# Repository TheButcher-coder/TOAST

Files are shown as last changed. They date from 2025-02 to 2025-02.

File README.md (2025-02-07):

# TOAST
TOtally Amazing Scales with blueTooth
The goal of this project is to make Bluetooth compatible scales, that connect to Espresso machines. 
Its primary goal is to be an alternative to expensive espresso scales with a timer.

# BOM
- Lolin32 esp32 Board with integrated lipo charger
- 2 1Kg Load cells with hx711 ADC boards
- 2 Capacitive touch buttons
- 1 MAX7219 driven 8 Letter 7 Segment display
- cables, prototype boards, 3d prints, ect...

Thanks to BOOKOO to make their scale software OS :) Check them out! https://github.com/kstam/esp-arduino-ble-scales
Also to warmack by implementing it on this set of HW before creating the GH

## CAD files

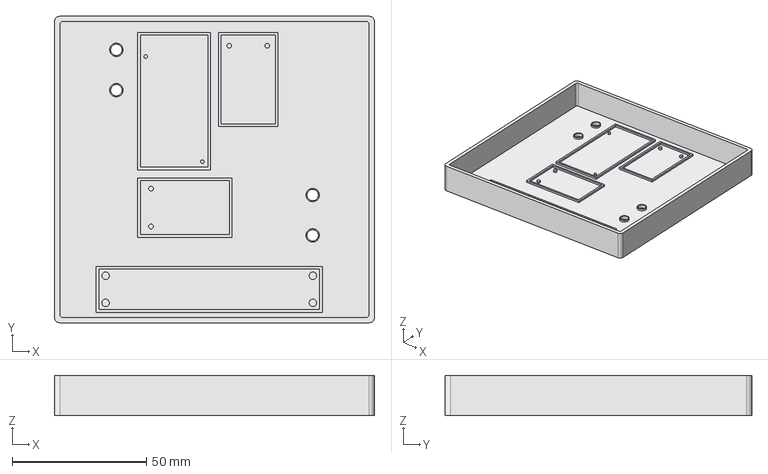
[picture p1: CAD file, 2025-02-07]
CAD/Prototyp/unteres gehäuse.FCStd
119.0 x 114.0 x 15.0 mm

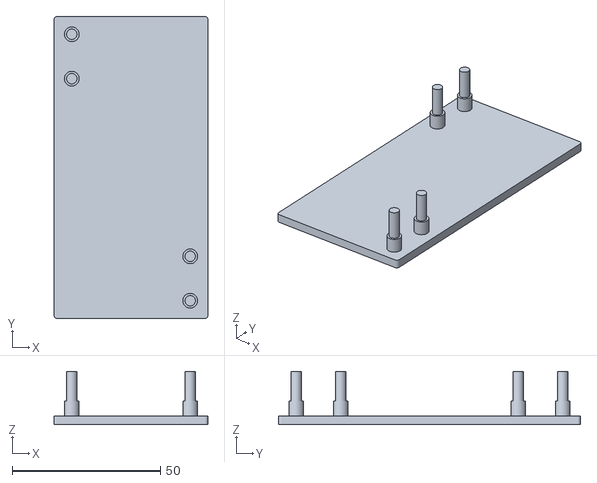
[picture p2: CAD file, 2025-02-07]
CAD/testplatte/unten-Körper.stl
52.0 x 102.0 x 18.0

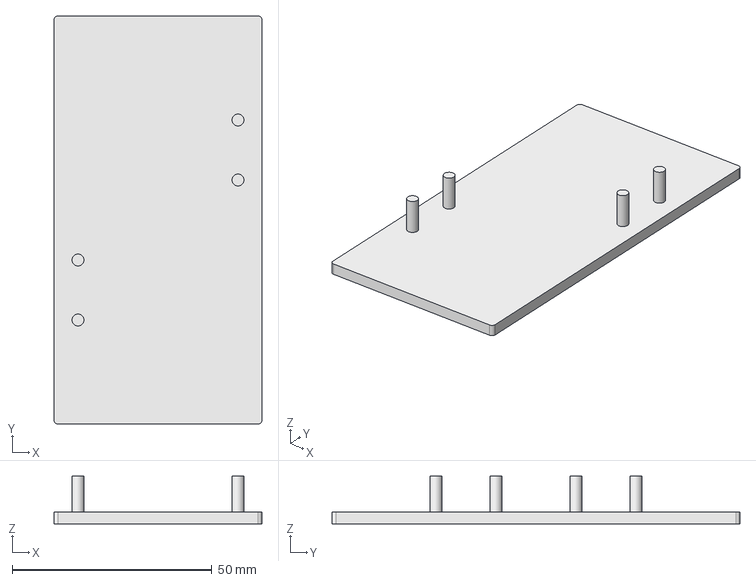
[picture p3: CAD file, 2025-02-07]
CAD/testplatte/unten.FCStd
52.0 x 102.0 x 12.0 mm

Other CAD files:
CAD/testplatte/unten-Körper001.stl

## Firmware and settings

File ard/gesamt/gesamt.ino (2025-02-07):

#include <Arduino.h>
#include <NimBLEDevice.h>
#include <SPI.h>
#include "HX711.h"

//BLE variables
static NimBLEServer* pServer;

//setting 20 byte weight value package based on https://github.com/BooKooCode/OpenSource/blob/main/bookoo_mini_scale%2Fprotocols.md
//functionality only to interface with: https://github.com/kstam/esp-arduino-ble-scales/tree/v3 
//values that never change are set below
uint8_t WEIGHT_DATA[20] = {0}; //initalizes an array with all values set to 0x00
uint8_t COMMAND_DATA[6] = {0};
const std::string TARE_COMMAND_STRING("\x03\x0A\x01\x00\x00\x08", 6);
//these could probably be handleded differently
const size_t WEIGHT_DATA_LENGTH = 20;
const size_t COMMAND_DATA_LENGTH = 6;

// HX711 pin assignment
const int LOADCELL1_DOUT_PIN = 4;
const int LOADCELL1_SCK_PIN = 5;

const int LOADCELL2_DOUT_PIN = 16;
const int LOADCELL2_SCK_PIN = 5;

HX711 scale1, scale2;

// Pins für MAX7219-Verbindung
#define DATA_PIN  22   // DIN-Pin des MAX7219
#define CLK_PIN   23   // CLK-Pin des MAX7219
#define CS_PIN     19   // CS-Pin des MAX7219

// MAX7219-Befehle
#define MAX7219_REG_NOOP        0x00
#define MAX7219_REG_DIGIT0      0x01
#define MAX7219_REG_DIGIT1      0x02
#define MAX7219_REG_DIGIT2      0x03
#define MAX7219_REG_DIGIT3      0x04
#define MAX7219_REG_DIGIT4      0x05
#define MAX7219_REG_DIGIT5      0x06
#define MAX7219_REG_DIGIT6      0x07
#define MAX7219_REG_DIGIT7      0x08
#define MAX7219_REG_DECODEMODE  0x09
#define MAX7219_REG_INTENSITY   0x0A
#define MAX7219_REG_SCANLIMIT   0x0B
#define MAX7219_REG_SHUTDOWN    0x0C
#define MAX7219_REG_DISPLAYTEST 0x0F

void setup() {
    Serial.begin(9600);

    //Init 7 Seg
    pinMode(CS_PIN, OUTPUT);
    SPI.begin(CLK_PIN, -1, DATA_PIN, CS_PIN);
    // MAX7219 initialisieren
    sendCommand(MAX7219_REG_SCANLIMIT, 0x07);   // Alle 8 Stellen aktivieren
    sendCommand(MAX7219_REG_DECODEMODE, 0xFF);  // 7-Segment-Decodierung aktivieren
    sendCommand(MAX7219_REG_INTENSITY, 0x08);   // Helligkeit einstellen
    sendCommand(MAX7219_REG_SHUTDOWN, 0x01);    // Normaler Betrieb


    //initialize scale
    scale1.begin(LOADCELL1_DOUT_PIN, LOADCELL1_SCK_PIN);
    scale2.begin(LOADCELL2_DOUT_PIN, LOADCELL2_SCK_PIN);

    scale1.set_scale(1265);  // Adjust this value based on calibration.
    scale2.set_scale(1265);
    scale1.tare();  // Reset the scale to 0
    scale2.tare();

    //setting values in weight data array 
    WEIGHT_DATA[0] = 0x03; //PRODUCT NUMBER
    WEIGHT_DATA[1] = 0x0B; //TYPE
    WEIGHT_DATA[5] = 'g'; //unit of weight *note that I don't know if this is correct to set grams

    //BLE server setup//
    //Setup to emulate the BooKoo Mini BLE Transmission Protocol here: https://github.com/BooKooCode/OpenSource/blob/main/bookoo_mini_scale%2Fprotocols.md
    //Initalize the library
    NimBLEDevice::init("BOOKO");

    pServer = NimBLEDevice::createServer();
    
    NimBLEService* pWeightService = pServer->createService("0FFE");
    

    NimBLECharacteristic* pWeightCharacteristic = pWeightService->createCharacteristic("FF11", NIMBLE_PROPERTY::READ | NIMBLE_PROPERTY::NOTIFY, 20); //weight command characteristic
    pWeightCharacteristic->setValue(WEIGHT_DATA);

    NimBLECharacteristic* pCommandCharacteristic = pWeightService->createCharacteristic("FF12", NIMBLE_PROPERTY::READ | NIMBLE_PROPERTY::WRITE | NIMBLE_PROPERTY::NOTIFY, 6);
    pCommandCharacteristic->setValue(COMMAND_DATA);

    // Start the services when finished creating all Characteristics and Descriptors //
    pWeightService->start();

    NimBLEAdvertising* pAdvertising = NimBLEDevice::getAdvertising();
    pAdvertising->addServiceUUID("0FFE"); // advertise the UUID of our service
    pAdvertising->setName("BOOKO"); // advertise the device name
    pAdvertising->start(); 
}


void loop() { //would be nice to move some of this code to functions for readability
    //reads scale in grams based on scale factor
    float weight1 = scale1.get_units();
    float weight2 = scale2.get_units();
    //Serial output of load cells for manual calibration. Calibration could be improved so you aren't just guessing and checking the scale factor and then reflashing but that seems hard
    Serial.print("weight: ");
    Serial.println(weight1 + weight2);

    //Updates weight data if BLE is connected and service is running
    if (pServer->getConnectedCount()) {
      Serial.println("Client connected");
      
      NimBLEService* pSvc = pServer->getServiceByUUID("0FFE");
      
      if (pSvc) {
        NimBLECharacteristic* pCChr = pSvc->getCharacteristic("FF12");
        NimBLECharacteristic* pWChr = pSvc->getCharacteristic("FF11");

        //checks for tare command,adjusts tare value if tare command is present, resets command value after tare is complete
        if (pCChr) {
          std::string COMMAND = pCChr->getValue();
          Serial.print("COMMAND: ");
          for (size_t i = 0; i < COMMAND.length(); i++) {
              Serial.print("0x");
              Serial.print((uint8_t)COMMAND[i], HEX);
              Serial.print(" ");
          }
            if (COMMAND == TARE_COMMAND_STRING) {
            scale1.tare();
            scale2.tare();
            uint8_t zeroCommand[COMMAND_DATA_LENGTH] = {0};
            pCChr->setValue(zeroCommand, COMMAND_DATA_LENGTH);
            Serial.println("TARED");
            }
        
        //Updates WEIGHT_DATA
          if (pWChr) {
            int32_t weightInt = static_cast<int32_t>((weight1+weight2) * 100); // Multiply by 100 to preserve 2 decimal places
            WEIGHT_DATA[6] = (weightInt < 0) ? 45 : 43; // '-' for negative, '+' for positive
            uint32_t absWeight = static_cast<uint32_t>(abs(weightInt));
            WEIGHT_DATA[7] = (absWeight >> 16) & 0xFF;
            WEIGHT_DATA[8] = (absWeight >> 8) & 0xFF;
            WEIGHT_DATA[9] = absWeight & 0xFF;

            //update checksum
            uint8_t checksum = 0;
            for (size_t i = 0; i < WEIGHT_DATA_LENGTH - 1; ++i) {
                checksum ^= WEIGHT_DATA[i];
            }
            WEIGHT_DATA[19] = checksum;
            pWChr->setValue(WEIGHT_DATA, sizeof(WEIGHT_DATA));
            pWChr->notify();
            Serial.println("Weight data sent via BLE.");
          }
        }
      }
    }
    //Write data to 7 Segment
    print_format_scale(weight1 + weight2);
    delay(100); //TODO tuning of delay and implementation of powersaving via sleep() or some other function.
}



void print_format_scale(double num) {
 //displayLeftWithComma(formatted, -1);
      if(num < 0) num = 0;
      if(num < 10) {
        displayLeftWithComma(num*10, 1);
      }
      else if(num  < 100) {
        displayLeftWithComma(num*10, 1);
      }
      else if(num  < 1000) {
        displayLeftWithComma(num*10, 1);
      }
}

// Funktion zur Steuerung der linken vier Stellen mit Komma
void displayRightWithComma(uint16_t number, uint8_t commaPosition) {
    for (int i = 0; i < 4; i++) {
        uint8_t digit = number % 10;           // Extrahiere die letzte Ziffer
        if (i == commaPosition) {
            digit |= 0b10000000;               // Dezimalpunkt aktivieren
        }
        sendCommand(MAX7219_REG_DIGIT0 + i, digit); // Digit3 bis Digit0 (linke Seite)
        number = (number-digit)/10;
    }
}

// Funktion zur Steuerung der rechten vier Stellen mit Komma
void displayLeftWithComma(uint16_t number, uint8_t commaPosition) {
    for (int i = 0; i < 4; i++) {
        uint8_t digit = number % 10;           // Extrahiere die letzte Ziffer
        if (i == commaPosition) {
            digit |= 0b10000000;               // Dezimalpunkt aktivieren
        }
        sendCommand(MAX7219_REG_DIGIT4 + i, digit); // Digit7 bis Digit4 (rechte Seite)
        number /= 10;
    }
}

// Funktion zum Senden von Befehlen an den MAX7219
void sendCommand(uint8_t reg, uint8_t data) {
    digitalWrite(CS_PIN, LOW);               // Chip-Select aktivieren
    SPI.transfer(reg);                       // Register senden
    SPI.transfer(data);                      // Daten senden
    digitalWrite(CS_PIN, HIGH);              // Chip-Select deaktivieren
}

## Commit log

2025-02-07 added all arduino Files
2025-02-07 Added some CAD files(FreeCad)
    [unten-Körper.stl, unten-Körper001.stl, unten.FCStd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]
2025-02-07 Revert "Added some CAD files(FreeCad)"
    This reverts commit bd0993b30330b4e386ff001ba7d89155821878a1.
    [unten-Körper.stl, unten-Körper001.stl, unten.FCStd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]
2025-02-07 Added CAD ffiles
    [unten-Körper.stl, unten-Körper001.stl, unten.FCStd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]
